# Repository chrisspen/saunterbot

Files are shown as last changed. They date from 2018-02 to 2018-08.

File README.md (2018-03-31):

Saunterbot
==========

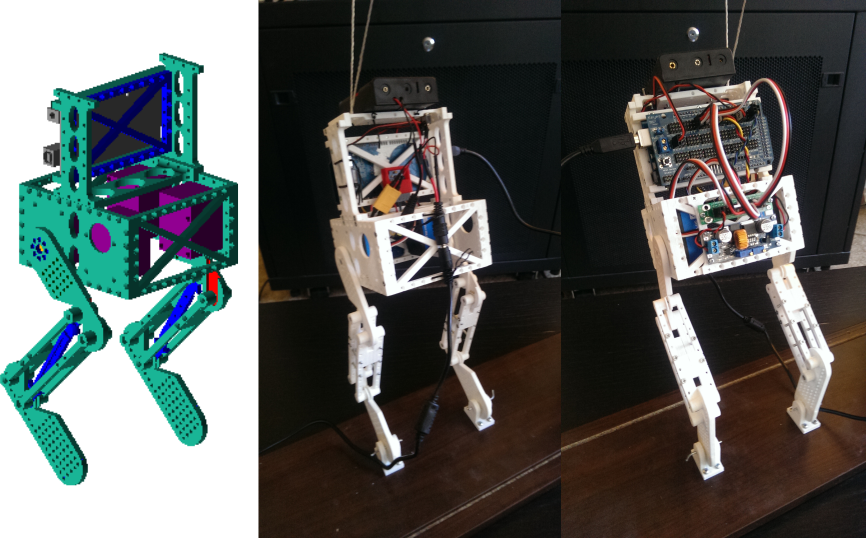
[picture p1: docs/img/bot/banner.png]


This is a small ROS-based platform for experimenting with dynamic biped balancing algorithms.

The image on the left is a CAD mock-up of the planned autonomous biped walker. On the right is the implemented version, mounted in a harness for testing its balancing ability.

An Arduino Mega is used for on-board actuation of servos and reading an MPU6050 accelerometer. It communicates to an external computer running ROS via USB for debugging and analyzing sensor output.

Once the basic balancing algorithm has been refined, the external computer will be replaced with a small single-board computer, like the Raspberry Pi, mounted in the compartment adjacent to the Arduino to make the platform fully autonomous.

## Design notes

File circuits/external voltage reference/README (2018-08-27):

Provides a stable high-accuracy voltage reference for the Arduino's ADC, using an LM4040 zener diode circuit.

http://www.skillbank.co.uk/arduino/measure.htm

The Arduino's on-board voltage references have a variance of +/- 5%.

Using the LM4040, it provides a voltage of  4.096V ± 0.2%.

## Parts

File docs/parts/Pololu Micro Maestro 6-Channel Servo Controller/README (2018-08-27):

Pololu Micro Maestro 6-Channel Servo Controller
===============================================

https://www.pololu.com/product/1350

https://www.pololu.com/docs/0J40

https://www.pololu.com/blog/456/maestro-servo-controller-arduino-library

https://github.com/pololu/maestro-arduino

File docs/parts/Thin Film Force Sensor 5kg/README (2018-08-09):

1 Pc DF 9-40 High Precise Force Sensing Resistor Thin Film Force Pressure Sensor (0-5kg)

https://www.amazon.com/Precise-Sensing-Resistor-Pressure-Sensor/dp/B07B68BHSH

Specifications:

Measuring Range: 0-500g, 0-2kg, 0-5kg, 0-10kg, 0-20kg (Optional)
Thickness: <0.25mm
Precision: ±2.5%(85% measuring range)
Repeatability: <±5.8(50% load)
Lifespan: >1million times
Initial Resistance: >10MΩ(no load)
Response Time: <1ms
Restore Time: <15ms
Test Voltage: DC 3.3V (typical)
EMI: Not generate
EDS: Not sensitive

Sensing Area Outer Diameter: 9mm
Sensing Area Inner Diameter: 7.5mm
Pin Spacing: 2.54mm

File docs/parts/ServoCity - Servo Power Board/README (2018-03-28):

ServoCity Servo Power Board

https://www.servocity.com/servo-power-board-unassembeld-with-pins-and-male-servo-leads

Product Weight  1.12 oz
Number of Channels  8 channel
Wire Gauge  22 AWG
Wire Length     6"
Max Current Per Channel     3A per channel continuous / up to 9A total

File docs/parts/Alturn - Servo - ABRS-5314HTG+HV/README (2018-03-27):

Alturn USA Servo ABRS-5314HTG+HV
================================

http://alturn-usa.com/products/PDF/ABRS-5314HTG+HV.pdf

https://www.ebay.com/itm/ABRS-5314HTG-Full-HV-Advance-Robot-Brushless-Digital-High-Voltage-HS-TG-/273065742269

https://www.robot-r-us.com/vmchk/motor-robot-servo/digital-metal-gear-ultra-high-torque-robot-servo-53-kg.cm-/-280.html

Weight:
        
    75grams / 2.60oz
    without splined horn

Dimensions:

    43 × 32× 32.5 mm
    (1.69 x 1.25 x 1.28 inch)

Torque At 7.4V:

    25.1kg/cm , 348oz/in

Speed At 7.4V:

    0.18sec / 60 deg at no load

Torque At 8.3V:

    32.4kg/cm , 466oz/in

Speed At 8.3V:

    0.16sec / 60 deg at no load

Torque At 12V:

    53.1kg/cm , 708z/in

Speed At 12V:

    0.14sec / 60 deg at no load

Motor Type:

    Japan Brushless motor

Potentiometer Type  

FSE11-4 Slider/indirect drive
Amplifier Type  6A Treble Power MOS-FET
Wire Info (Black)   - Negative
Wire Info (Red) + Positive
Wire Info (White)   S Single
Gear Types  Stainless Steel
Travel Degree   280 degree / 0.9us ~ 2.1us PWM
Operation Voltage   7.4V ~ 12V (2S ~ 3S Li Poly)

Cable pinout:

    Note, it appears to have a "J" or Futaba connector, which has a tab indicating polarity.

    Starting with notched end: white/red/black

Testing:

    At 5V, I found the servo to have an astonishing 280 degrees of rotation. However, it was also incredibly noisy.

    At 10V, I found the servo performed almost the same, but had a noticable stutter once or twice a cycle.

    input Voltage is 6.0 ~ 12.0V
    best voltage is 7.4 ~ 8.4V

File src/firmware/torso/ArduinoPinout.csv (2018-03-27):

Arduino Pin | Interruptable | Supported Modes | Mode | PWM | Function | Label | Label Color | Variable | Wire Color | Notes
D0 |  | NA | NA |  | USB
D1 |  | NA | NA |  | USB
D2 |  | input/output |  | 1
D3 |  | input/output |  | 1
D4 |  | input/output |  | 1
D5 |  | input/output |  | 1
D6 |  | input/output |  | 1
D7 |  | input/output |  | 1
D8 |  | input/output |  | 1
D9 |  | input/output |  | 1
D10 |  | input/output |  | 1
D11 |  | input/output |  | 1
D12 |  | input/output |  | 1
D13 |  | input/output |  | 1 | status LED | SL |  | STATUS_LED_PIN |  | Note, has built-in LED, so can't reliably be used as an input.
D14 |  | input/output |  |  | push button | PB1 |  | PUSH_BUTTON_PIN |  | Simple push button.
D15 |  | input/output
D16 |  | input/output
D17 |  | input/output
D18 |  | input/output
D19 |  | input/output
D20 |  | input/output |  |  | SDA |  |  |  |  | I2C
D21 |  | input/output |  |  | SCL |  |  |  |  | I2C
D22 |  | input/output
D23

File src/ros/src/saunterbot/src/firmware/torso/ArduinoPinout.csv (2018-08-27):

Arduino Pin | Interruptable | Supported Modes | Has ADC | Mode | PWM | Function | Label | Label Color | Variable | Wire Color | Implemented | Notes
D0 |  | NA |  | NA |  | USB
D1 |  | NA |  | NA |  | USB
D2 |  | input/output |  | input |  | IMU interrupt | INT |  |  | yellow | 1 | IMU interrupt.
D3 |  | input/output |  |  | 1
D4 |  | input/output |  |  | 1
D5 |  | input/output |  |  | 1
D6 |  | input/output |  |  | 1
D7 |  | input/output |  | output | 1 | servo hip right | SHR |  | SERVO_HIP_RIGHT_PIN |  | 1
D8 |  | input/output |  | output | 1 | servo hip left | SHL |  | SERVO_HIP_LEFT_PIN |  | 1
D9 |  | input/output |  | output | 1 | servo knee right | SKR |  | SERVO_KNEE_RIGHT_PIN |  | 1
D10 |  | input/output |  | output | 1 | servo knee left | SKL |  | SERVO_KNEE_LEFT_PIN |  | 1
D11 |  | input/output |  |  | 1 | servo ankle right |  |  |  |  | 0
D12 |  | input/output |  |  | 1 | servo ankle left |  |  |  |  | 0
D13 |  | input/output |  | output | 1 | status LED | SL |  | STATUS_LED_PIN |  | 1 | Note, has built-in LED, so can't reliably be used as an input.
D14 |  | input/output
D15 |  | input/output
D16 |  | input/output
D17 |  | input/output |  | input |  | push button | PB1 |  | PUSH_BUTTON_PIN |  | 1 | Simple push button.
D18 |  | input/output |  |  |  |  |  |  |  |  |  | TX (required for Maestro)
D19 |  | input/output |  |  |  |  |  |  |  |  |  | RX (optional for Maestro)
D20 |  | input/output |  | I2C |  | SDA | SDA |  |  | green | 1 | I2C, IMU
D21 |  | input/output |  | I2C |  | SCL | SCL |  |  | blue | 1 | I2C, IMU
D22 |  | input/output
D23 |  | input/output
A0 |  | input/output | 1
A1 |  | input/output | 1
A2 |  | input/output | 1
A3 |  | input/output | 1
A4 |  | input/output | 1 | input |  | feedback hip right | FHR |  | FEEDBACK_HIP_RIGHT_PIN | green | 1
A5 |  | input/output | 1 | input |  | feedback hip left | FHL |  | FEEDBACK_HIP_LEFT_PIN | green | 1
A6 |  | input/output | 1 | input |  | feedback knee right | FKR |  | FEEDBACK_KNEE_RIGHT_PIN | green | 1
A7 |  | input/output | 1 | input |  | feedback knee left | FKL |  | FEEDBACK_KNEE_LEFT_PIN | green | 1
A8 |  | input/output | 1 | input |  | feedback knee deflection right | KDR |  | FEEDBACK_KNEE_DEFLECTION_RIGHT_PIN | white | 1
A9 |  | input/output | 1 | input |  | feedback knee deflection left | KDL |  | FEEDBACK_KNEE_DEFLECTION_LEFT_PIN | white | 1
A10 |  | input/output | 1
A11 |  | input/output | 1
A12 |  | input/output | 1
A13 |  | input/output | 1
A14 |  | input/output | 1
A15 |  | input/output | 1

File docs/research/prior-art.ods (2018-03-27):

Name | DOF per leg | Number of legs | Balancing | Complete | URL
Rofi | 6 | 2 | static | 1 | http://www.projectbiped.com/prototypes/rofi
Fobo | 4 | 2 | static | 1 | http://www.projectbiped.com/prototypes/fobo
Kame | 2 | 4 | static | 1 | https://www.thingiverse.com/thing:1265766
Experimental Quadraped | 2 | 4 | unknown | 0 | https://www.thingiverse.com/thing:652121
Eyepot | 2 | 4 | static | 1 | https://www.thingiverse.com/thing:2830304

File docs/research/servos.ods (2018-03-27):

Score | Name | Price | Speed (sec/90deg) | Torque (kg*cm) | Voltage | Metal Gears | URL | Notes
1.27 | ABRS-5314HTG+Full HV | $48 | 0.14 | 53 | 12 | 1 | https://www.ebay.com/itm/ABRS-5314HTG-Full-HV-Advance-Robot-Brushless-Digital-High-Voltage-HS-TG-/273065742269
1.12 | Digital Metal Gear Ultra High Torque Robot Servo 53 | $70 | 0.14 | 53.1 | 12 | 1 | https://www.robot-r-us.com/vmchk/motor-robot-servo/digital-metal-gear-ultra-high-torque-robot-servo-53-kg.cm-/-280.html | Only have one left I stock. Of course... alturn usa servo 53 280
1.09 | ABRS-8034HTG+Full HV | $58 | 0.18 | 80 | 12 | 1 | https://www.ebay.com/itm/ABRS-8034HTG-HV-Duty-Heavy-Robot-Brushless-Digital-High-Voltage-HS-TG-/273065742956
0.00 | Power HD 1235MG | $60 | 0.18 | 40 | 7.4 | 1 | https://www.pololu.com/product/2375
0.00 | FEETECH FT5335M | $40 | 0.18 | 40 | 7.4 | 1 | https://www.pololu.com/product/3429
0.00 | HS-7950TH | $150 | 0.13 | 35 | 7.4 | 1 | https://www.servocity.com/hs-7950th-servo
-0.25 | CM-D950TW-180 Servo Gearbox | $208 | 0.28 | 70 | 7.4 | 1 | https://www.servocity.com/cm-d950tw-180-servo-gearbox#197=7&198=9&439=475&440=476
-0.46 | CM-9380TH-180 Servo Gearbox 2:1 | $240 | 0.28 | 69 | 7.4 | 1 | https://www.servocity.com/cm-9380th-180-servo-gearbox#197=7&198=9&439=475&440=476 | Price servo=180, price gearbox=100 => total=280
-0.60 | 4.5-9380TH-180 Servo Gearbox | $260 | 0.28 | 68 | 7.4 | 1 | https://www.servocity.com/4-5-9380th-180-servo-gearbox
-0.81 | TM-805MG-180 Servo Gearbox | $170 | 0.53 | 94 | 6 | 1 | https://www.servocity.com/tm-805mg-180-servo-gearbox
-0.83 | i00800 Torxis Servo | $290 | 0.75 | 1600 | 12 | 1 | https://www.pololu.com/product/1391
-1.42 | HS-1005SGT Servo | $435 | 0.19 | 110 | 14.8 | 1 | https://www.servocity.com/hs-1005sgt-servo
-1.57 | 4.5-D645MW-180 Tube Mount Servo Gearbox | $120 | 0.85 | 65 | 7.4 | 1 | https://www.servocity.com/4-5-d645mw-180-tube-mount-servo-gearbox#197=4&198=9&439=475&440=476
-1.86 | HS-1100WP Servo | $500 | 0.19 | 110 | 14.8 | 1 | https://www.servocity.com/hs-1100wp-servo
-2.70 | CM-785HB Servo Gearbox | $130 | 1.17 | 66 | 6 | 1 | https://www.servocity.com/cm-785hb-servo-gearbox

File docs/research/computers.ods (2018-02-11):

score | name | available | cost | cpu cores | cpu ghz | arch type | arch bits | memory type | memory GB | video | wifi | bluetooth | ethernet | powered from usb | usb | usb type | audio | mic | storage type | max storage (GB) | width (mm) | depth (mm) | area (mm^2) | power voltage | power mA | power watts | pin voltage | SATA | micro SD | arduino compatible | digital pins | analog pins | GVS | URL
26.35 | Raspberry Pi 3 | 1 | $35 | 4 | 1.2 | ARM | 64 | DDR2 | 1 | HDMI | 1 | 1 | 1 | 1 | 4 | 2 | 1 | 1 | micro SD | 64 | 85 | 56 | 4760 | 5 | 700 | 3.5 | 3.3 | 0 | 1 | 0 | 40 | 0 | 1 | https://www.raspberrypi.org/blog/raspberry-pi-3-on-sale/
23.64 | Raspberry Pi 2 Model B | 1 | $35 | 4 | 0.9 | ARM | 32 | DDR2 | 1 | HDMI | 0 | 0 | 1 | 1 | 4 | 2 | 1 | 0 | micro SD | 64 | 86 | 56 | 4816 | 5 | 700 | 3.5 | 3.3 | 0 | 1 | 0 | 40 | 0 | 1 | http://www.raspberrypi.org/products/raspberry-pi-2-model-b/
23.05 | Odroid-C1 | 1 | $35 | 4 | 1.5 | ARM | 32 | DDR3 | 1 | HDMI | 0 | 0 | 1 | 0 | 4 |  | 1 | 0 | micro SD | 64 | 85 | 56 | 4760 | 5 | 500 | 2.5 | 3.3 | 0 | 1 | 0 | 40 | 2 | 1 | http://www.hardkernel.com/main/products/prdt_info.php
22.28 | Orange Pi 2 | 1 | $35 | 4 | 1.6 | ARM | 32 | DDR3 | 1 | HDMI | 1 | 0 | 1 | 1 | 4 | 2 | 1 | 1 | micro SD | 64 | 60 | 93 | 5580 | 5 | 700 | 3.5 | 3.3 |  | 1 | 0 | 40 | 0 | 0 | http://www.cnx-software.com/2015/03/21/orange-pi-2-allwinner-h3-quad-core-development-board-sells-for-35/
20.78 | Orange Pi | 1 | $15 | 4 | 1.6 | ARM | 32 | DDR3 | 1 | HDMI | 0 | 0 | 1 | 1 | 3 | 2 | 1 | 1 | micro SD | 64 | 60 | 93 | 5580 | 5 | 700 | 3.5 | 3.3 |  | 1 | 0 | 40 | 0 | 0 | http://liliputing.com/2015/08/orange-pi-pc-is-a-15-single-board-computer.html
20.33 | UDOO Dual Basic | 1 | $100 | 2 | 1 | ARM | 32 | DDR3 | 1 | HDMI | 0 | 0 | 1 | 1 | 2 |  | 1 | 1 | micro SD | 64 | 110 | 85 | 9350 | 5 | 660 | 3.3 | 3.3 | 0 | 1 | 1 | 62 | 14 | 1 | http://shop.udoo.org/usa/product/udoo-dual-basic.html
15.06 | Beagle Bone Black | 1 | $45 | 1 | 1 | ARM | 32 | DDR3 | 0.5 | HDMI | 0 | 0 | 1 | 1 | 1 |  | 1 | 0 | micro SD | 64 | 87 | 54 | 4698 | 5 | 500 | 2.5 | 3.3/5 | 0 | 1 | 0 | 65 | 7 | 0.5 | http://beagleboard.org/BLACK
9.43 | PCDuino3 | 1 | $60 | 1 | 1 | ARM | 32 | DRAM | 1 | HDMI | 0 | 0 | 1 | 1 | 1 |  | 1 | 0 | micro SD | 64 | 121 | 65 | 7865 | 5 | 2000 | 10 | 3.3 | 1 | 1 | 1 | 14 | 6 | 1 | http://www.sainsmart.com/arduino/control-boards/pcduino3.html
5.00 | Arduino TRE | 0 |  | 1 | 1 | ARM | 32 | DDR3 | 0.5 | HDMI | 0 | 0 | 1 | 1 | 4 |  | 1 | 0 | micro SD | 64 |  |  | 0 |  |  | 0 | 3.3/5 | 0 | 1 | 1 | 14 | 6 | 1 | http://arduino.cc/en/Main/ArduinoBoardTre
5.00 | Arduino Yun | 0 | $58 | 1 | 0.4 | MIPS | 32 | DDR2 | 0.064 | 0 | 1 | 0 | 1 | 1 | 1 |  | 0 | 0 | micro SD | 64 | 73 | 53 | 3869 | 5 | 300 | 1.5 | 3.3 | 0 | 1 | 1 | 20 | 12 | 1 | http://arduino.cc/en/Main/ArduinoBoardYun?from=Products.ArduinoYUN
0.36 | Intel Galileo Gen 1 | 1 | $80 | 1 | 0.4 | x86 | 32 | DRAM | 0.25 | 0 | 0 | 0 | 1 | 1 | 1 |  | 0 | 0 | micro SD | 64 | 124 | 72 | 8928 | 5 | 3000 | 15 | 3.3/5 | 0 | 1 | 1 | 14 | 6 | 1
0.36 | Intel Galileo Gen 2 | 1 | $80 | 1 | 0.4 | x86 | 32 | DRAM | 0.25 | 0 | 0 | 0 | 1 | 1 | 1 |  | 0 | 0 | micro SD | 64 | 124 | 72 | 8928 | 5 | 3000 | 15 | 3.3/5 | 0 | 1 | 1 | 14 | 6 | 1 | http://arduino.cc/en/ArduinoCertified/IntelGalileo
-138.81 | AIMB-281G2-00A1E Mini-ITX | 1 | $241 | 4 | 3.9 | x86 | 64 | DDR3 | 8 | VGA/DVI | 0 | 0 | 1 | 1 | 8 | 2 | 1 | 1 | micro SD | 64 | 170 | 170 | 28900 |  |  | 186.127 |  | 1 | 0 | 0 | 0 | 0 | 0 | http://buy.advantech.com/Mini+ITX+industrial+motherboard/AIMB+281G2+00A1E/model-AIMB-281G2-00A1E.htm

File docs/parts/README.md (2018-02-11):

Folder Format
-------------

Manufacturer - Product - Version

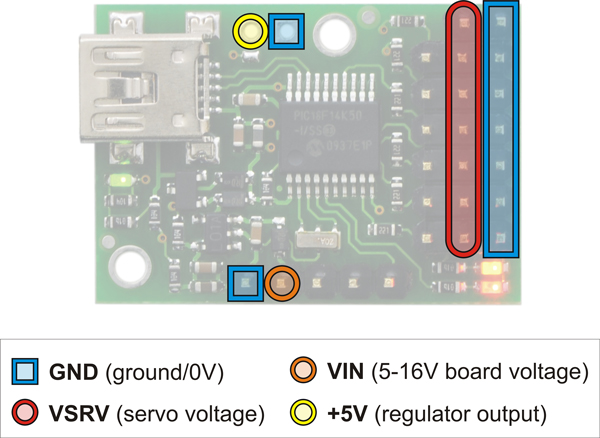
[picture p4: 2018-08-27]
docs/parts/Pololu Micro Maestro 6-Channel Servo Controller/0J2352.1200.jpg

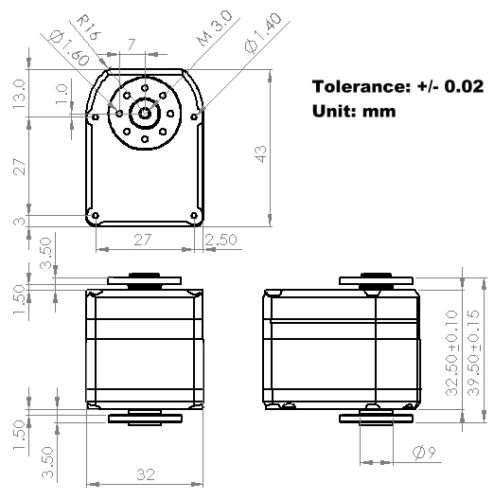
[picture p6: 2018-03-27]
docs/parts/Alturn - Servo - ABRS-5314HTG+HV/s-l500.jpg

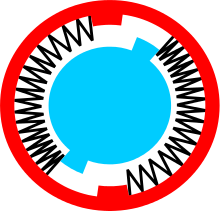
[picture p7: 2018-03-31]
docs/parts/Servo Saver/DMF.svg.png

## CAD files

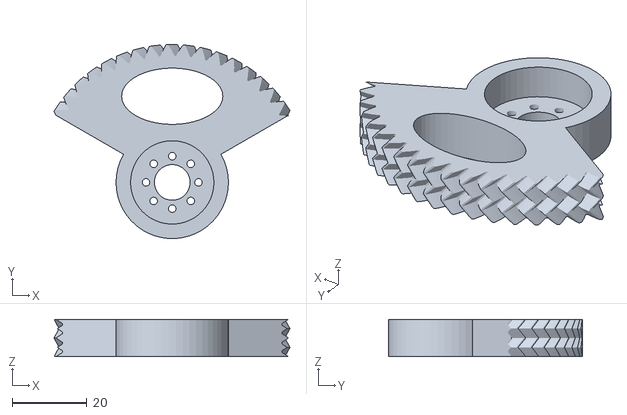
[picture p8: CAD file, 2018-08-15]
models/printable/leg_hip_gear_main.stl
63.0 x 51.8 x 10.0

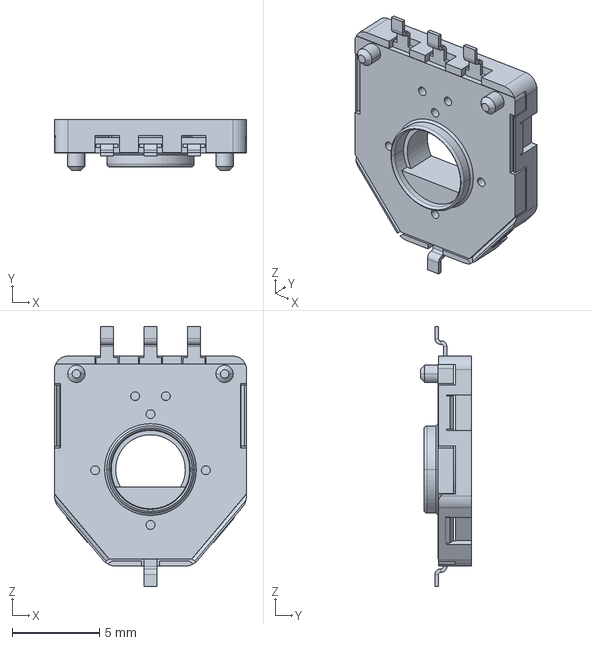
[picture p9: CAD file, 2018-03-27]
docs/parts/Rotary Position Sensor - Model 3382/3382g-001-xxx.stp
11.0 x 2.95 x 14.9 mm

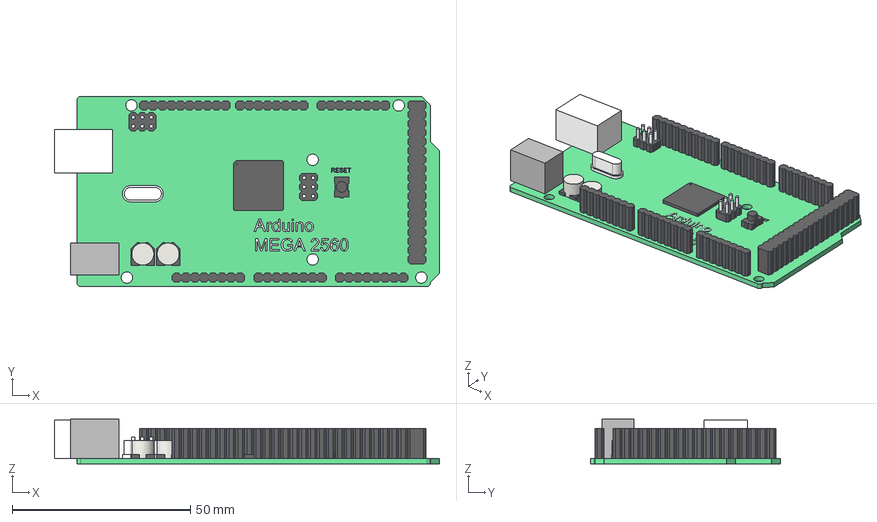
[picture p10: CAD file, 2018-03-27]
models/electronics/arduino-mega-2560/ArduinoMEGA2560.stp
107.9 x 53.3 x 12.6 mm

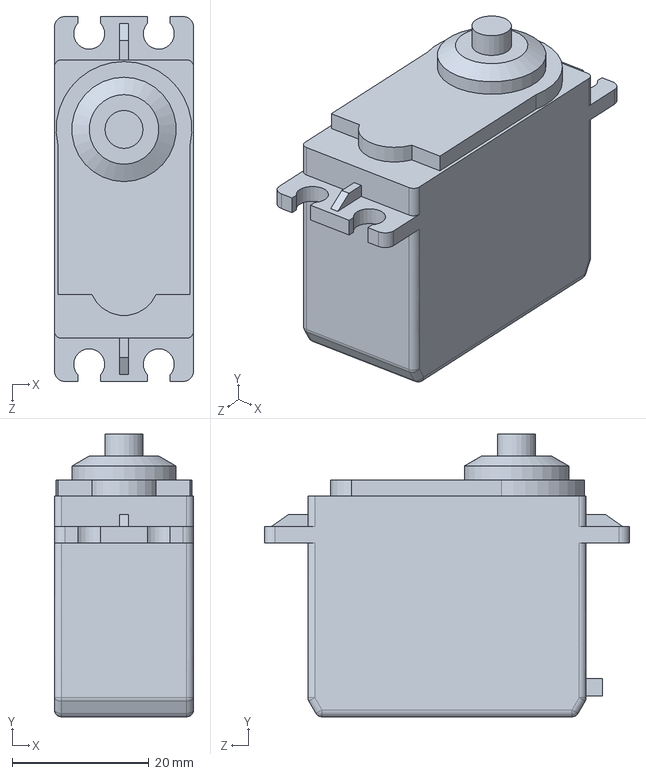
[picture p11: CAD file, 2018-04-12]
models/electronics/hs-311-hitec-standard-servo/HS-311 Hitec Standard Servo.SLDPRT
20.3 x 41.3 x 53.3 mm

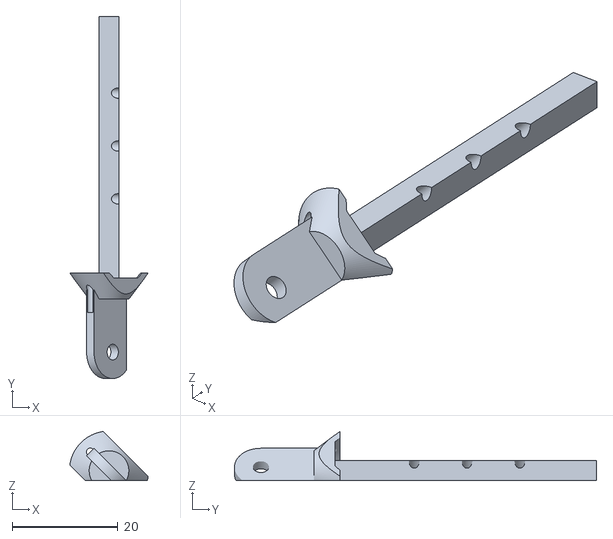
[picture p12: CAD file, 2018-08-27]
models/printable/leg_spring2_male.stl
14.8 x 68.5 x 9.30

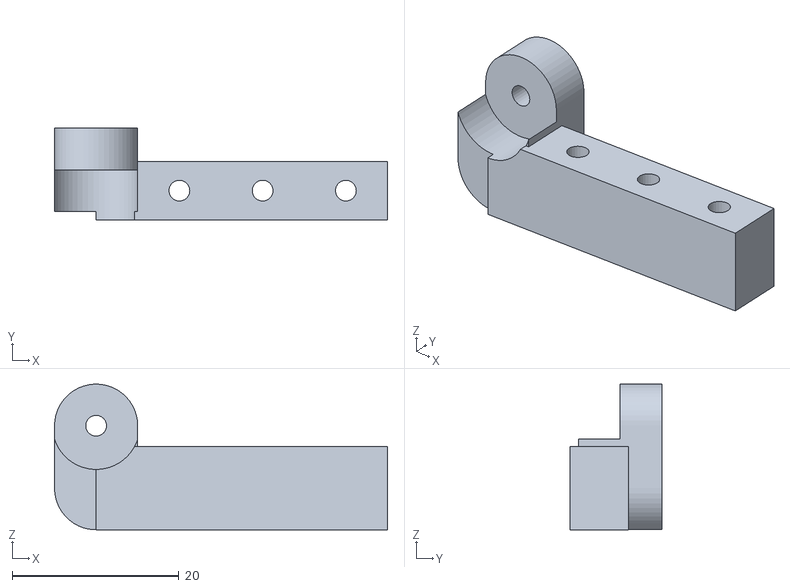
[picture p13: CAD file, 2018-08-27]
models/printable/leg_spring_hinge_extender.stl
40.0 x 11.0 x 17.5

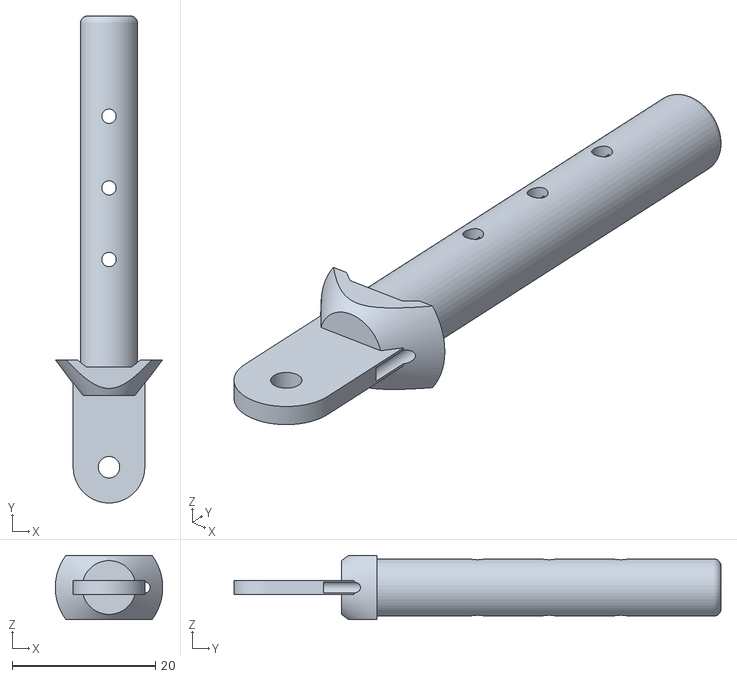
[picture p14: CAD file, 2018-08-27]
models/printable/leg_spring2_female.stl
15.0 x 68.0 x 9.00

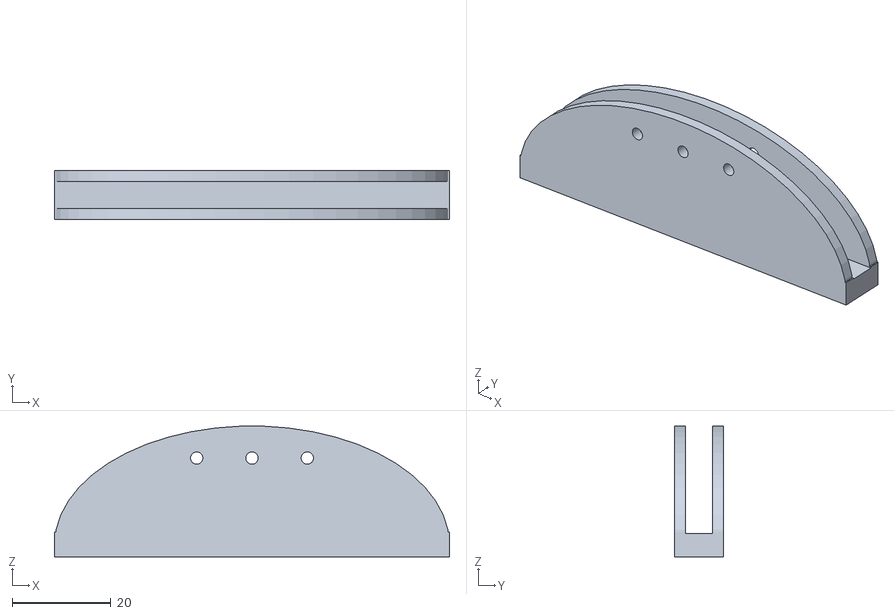
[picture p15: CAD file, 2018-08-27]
models/printable/foot_mock.stl
80.0 x 10.0 x 26.5

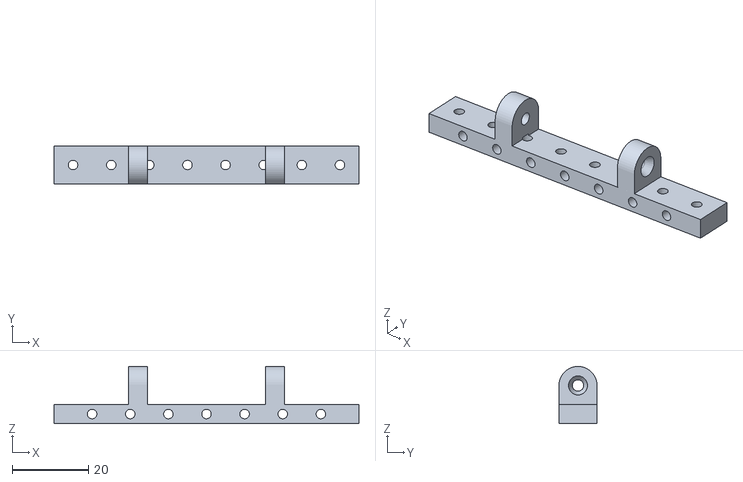
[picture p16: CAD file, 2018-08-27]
models/printable/foot_mock_core.stl
80.0 x 10.0 x 15.0

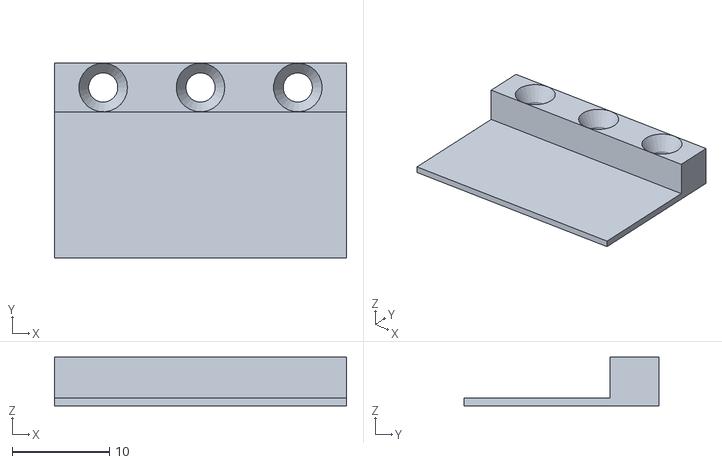
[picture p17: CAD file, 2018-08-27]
models/printable/foot_mock_toe_spring.stl
30.0 x 20.0 x 5.00

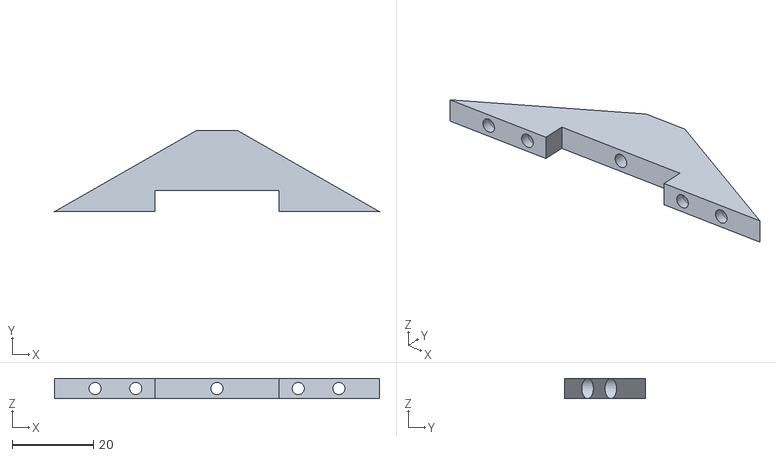
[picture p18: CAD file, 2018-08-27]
models/printable/foot_mock_toe.stl
80.0 x 20.0 x 5.00

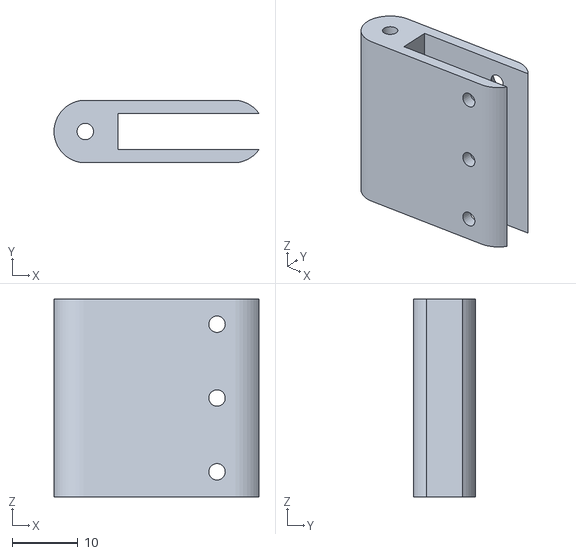
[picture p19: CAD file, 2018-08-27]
models/printable/foot_mock_ankle.stl
31.1 x 9.48 x 30.0

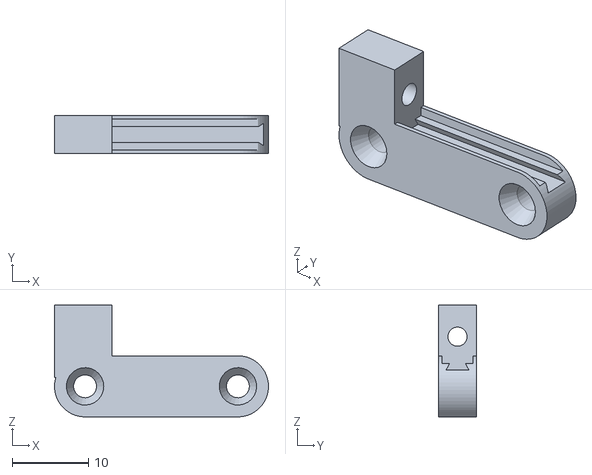
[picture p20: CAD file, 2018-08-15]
models/printable/leg_knee_tendon_anchor_bottom.stl
28.0 x 5.00 x 14.6

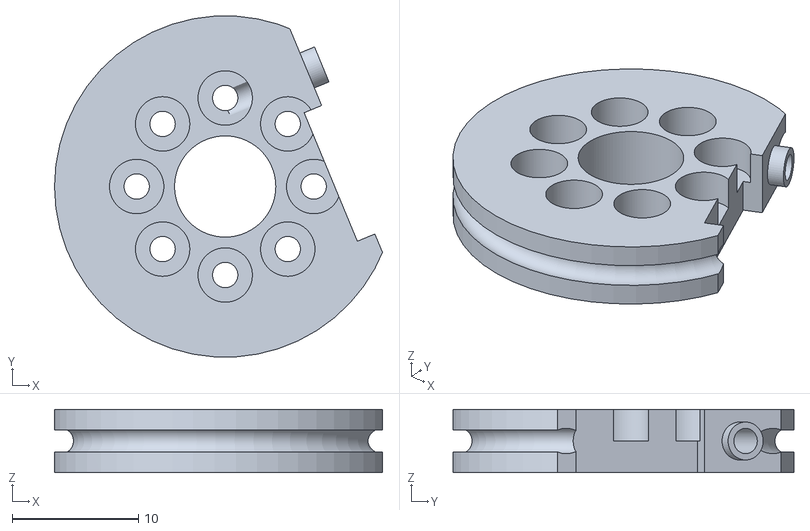
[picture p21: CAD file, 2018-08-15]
models/printable/leg_knee_servo_spindle.stl
25.9 x 26.9 x 5.00

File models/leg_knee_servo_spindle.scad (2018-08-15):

use <leg_knee_servo_riser.scad>;

rotate([0,180,0])
leg_knee_servo_spindle();

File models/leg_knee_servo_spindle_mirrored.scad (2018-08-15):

use <leg_knee_servo_riser.scad>;

mirror([0,0,1])
rotate([0,180,0])
leg_knee_servo_spindle();

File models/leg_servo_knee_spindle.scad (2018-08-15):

use <leg_knee_servo_riser.scad>;

leg_knee_servo_horn();

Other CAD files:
models/sensor.stl
models/printable/leg_spring_hinge_extender_mirrored.stl
models/printable/leg_spring.stl
models/printable/leg_hip_axle_round.stl
models/gears/parametric_involute_gear_v5.0.scad
models/arduino_mega_mount.scad
models/arduino_mega_mount_bottom.scad
models/arduino_mega_mount_top.scad
models/balancer.scad
models/balancer_bottom_plate.scad
models/balancer_drive_gear.scad
models/balancer_gear_axle_top.scad
models/balancer_gear_washer.scad
models/balancer_middle_plate.scad
models/balancer_opposite_gear.scad
models/balancer_top_plate.scad
models/balancer_translation_gear.scad
models/balancer_weight_container.scad
models/balancer_weight_container_door.scad
models/battery_holder_strut.scad
models/dc_converter_tray.scad
models/electronics/arduino-mega-2560/ArduinoMEGA2560.ipt
models/electronics/arduino-mega-2560/Arduino_MEGA2560.stl
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

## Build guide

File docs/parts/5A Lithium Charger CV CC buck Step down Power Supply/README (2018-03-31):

When you use the product, the module inputs and outputs to be isolated from ground！
Specifications
1、Input voltage range:6～38VDC(Note:input voltage not exceeding 38V)
2、Output voltage range:1.25-36VDC adjustable
3、Output current: 0-5A
4、Output power: 75W
5、High efficiency up to 96%
6、Built in thermal shutdown function
7、Built in current limit function
8、Built in output short protection function
9、Input reverse polarity protection: None (if required, high current diode in series with the input).
10、L x W x H =61.7*26.2*15mm
11、Weight: 20g

Application
1、Use as a step-down modules with overcurrent protection capabilities
Usage:
(1) adjust the “voltage potentiometer” so that the output voltage reaches the value you want.
(2) use a multimeter to measure the output short-circuit current with 10A stalls, while regulating the “current potentiometer” so that the output current reaches a predetermined overcurrent protection value. (For example, the meter displays the current value of 4A, then you can use the module to a maximum current of 4A)
(3) Connected to the load.

2、Use as a battery charger
Usage:
(1). Make sure you need to charge the battery float voltage and charging current; (if lithium parameters 3.7V/2200mAh, then the float voltage is 4.2V, the maximum charging current 1C, ie 2200mA)
(2). Under no-load conditions, adjust the “Voltage potentiometer” so that the output voltage reaches the float voltage; (if to 3.7V rechargeable lithium battery, the output voltage can be adjusted to 4.2V)
(3). use a multimeter to measure the output short-circuit current with 10A stalls, while regulating the “current potentiometer” so that the output current reaches a predetermined Charging current value.
(4). Charge turn lamp current factory default is 0.1 times the charging current; (Battery during charging current is gradually reduced, if the charge current setting is 1A, then when the charge current is less than 0.1A, blue lights turned off, the green light is on, which means that the battery is fully charged)
(5).connected to the battery charge.
(1,2,3,4 steps as: Output is unloaded, do not connect the battery)

3、Use as a LED constant current driver module
Usage:
(1). adjust the “voltage potentiometer” so that the output voltage reaches the value you want.
(2). use a multimeter to measure the output short-circuit current with 10A stalls, while regulating the “current potentiometer” so that the output current reaches a predetermined LED operating current.
(3). Connect LED, work.
(1,2 steps as: Output is unloaded, do not connect LED)

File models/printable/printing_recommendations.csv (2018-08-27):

filename | wall_thickness | color | infill_percent | platform_adhesion | support_type | obsolete
arduino_mega_mount.stl |  |  |  |  |  | 0
arduino_mega_mount_bottom.stl |  |  |  |  |  | 0
arduino_mega_mount_top.stl |  |  |  |  |  | 0
balancer_bottom_plate.stl |  |  |  |  |  | 0
balancer_drive_gear.stl |  |  |  |  |  | 0
balancer_gear_axle_top.stl |  |  |  |  |  | 0
balancer_gear_washer.stl |  |  |  |  |  | 0
balancer_middle_plate.stl |  |  |  |  |  | 0
balancer_opposite_gear.stl |  |  |  |  |  | 0
balancer_top_plate.stl |  |  |  |  |  | 0
balancer_translation_gear.stl |  |  |  |  |  | 0
balancer_weight_container.stl |  |  |  |  |  | 0
balancer_weight_container_door.stl |  |  |  |  |  | 0
battery_holder_strut.stl |  |  |  |  |  | 0
dc_converter_tray.stl |  |  |  |  |  | 0
foot_mock.stl |  |  |  |  |  | 0
foot_mock_ankle.stl |  |  |  |  |  | 0
foot_mock_core.stl |  |  |  |  |  | 0
foot_mock_toe.stl |  |  |  |  |  | 0
foot_mock_toe_spring.stl |  |  |  |  |  | 0
foot_pivot.stl |  |  |  |  |  | 0
leg_hip_axle.stl |  |  |  |  |  | 0
leg_hip_axle_round.stl |  |  |  |  |  | 0
leg_hip_gear_main.stl |  |  |  |  |  | 0
leg_hip_gear_main_34.stl |  |  |  |  |  | 1
leg_hip_holder.stl |  |  |  |  |  | 0
leg_hip_spacer.stl |  |  |  |  |  | 0
leg_hip_tendon_retainer.stl |  |  |  |  |  | 0
leg_knee_servo_riser.stl |  |  |  |  |  | 0
leg_knee_servo_spindle.stl |  |  |  |  |  | 0
leg_knee_servo_spindle_mirrored.stl |  |  |  |  |  | 0
leg_knee_tendon_anchor_bottom.stl |  |  |  |  |  | 0
leg_knee_tendon_anchor_bottom_mirrored.stl |  |  |  |  |  | 0
leg_knee_tendon_anchor_top.stl |  |  |  |  |  | 0
leg_lower.stl |  |  |  |  |  | 0
leg_middle.stl |  |  |  |  |  | 0
leg_middle_bottom_a.stl |  |  |  |  |  | 0
leg_middle_bottom_b.stl |  |  |  |  |  | 0
leg_middle_top_a.stl |  |  |  |  |  | 0
leg_middle_top_b.stl |  |  |  |  |  | 0
leg_servo_knee_spindle.stl |  |  |  |  |  | 1
leg_spring.stl |  |  |  |  |  | 0
leg_spring2.stl |  |  |  |  |  | 0
leg_spring2_female.stl |  |  |  |  |  | 0
leg_spring2_male.stl |  |  |  |  |  | 0
leg_spring_hinge_extender.stl |  |  |  |  |  | 0
leg_spring_hinge_extender_mirrored.stl |  |  |  |  |  | 0
leg_upper.stl |  |  |  |  |  | 0
leg_upper_mirrored.stl |  |  |  |  |  | 0
motors_alturn_abrs_5314htg_hv.stl |  |  |  |  |  | 0
pelvis_cross_support.stl |  |  |  |  |  | 0
pelvis_motor_face.stl |  |  |  |  |  | 0
pelvis_motor_face_mirrored.stl |  |  |  |  |  | 0
pelvis_torso_strut.stl |  |  |  |  |  | 0
torso_side.stl |  |  |  |  |  | 0

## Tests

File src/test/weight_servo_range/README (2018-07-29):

Sweeps the servo across its range when a button is pressed.

Compile and upload with:

    make && make upload

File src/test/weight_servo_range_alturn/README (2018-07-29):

Sweeps the servo across its range when a button is pressed.

Specialized for use with the heavy duty Alturn servo.

Compile and upload with:

    make && make upload

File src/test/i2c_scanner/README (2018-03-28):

Scans all devices on the I2C bus and prints their addresses to the serial port.

This is used to verify that the MPU6050 is correctly wired and responded to requests at the expected 0x68 address.

Build:

    makee && make upload

Run:

    make monitor

To exit:

    ctrl-a, then k, then "yes"

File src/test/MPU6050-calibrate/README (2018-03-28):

http://wired.chillibasket.com/2015/01/calibrating-mpu6050/

FOR CALIBRATION THE SENSOR MUST BE PLACED FLAT WITH Z POINTING UP.

The sketch outputs the required accelerometer and gyroscope offsets through the serial monitor. All you have to do is plug them into the initialisation code at the start of your program, and you are good to go! Please note that the required offsets vary significantly from sensor to sensor, so you have to repeat the calibration program above for each MPU-6050 sensor you are using.

Sensor readings with offsets:   7   -9  16375   0   -1  0
Your offsets:   -3984   -525    -849    17  147 54

Data is printed as: acelX acelY acelZ giroX giroY giroZ
Check that your sensor readings are close to 0 0 16384 0 0 0
If calibration was succesful write down your offsets so you can set them in your projects using something similar to mpu.setXAccelOffset(youroffset)

Test these values in MPU6050-read.

All of the values float a large amount at the start, especially the yaw data. This then stops after around 13 seconds, probably due to the completion of some auto-calibration process. I repeated this test a number of times and it seems that the sensor can take up to 40 seconds to complete its calibration, on some occasions. Therefore we should take this delay into account in our program. The robot should wait for around 40 seconds, before beginning to use the sensor and starting the main program.

Build:

    make && make upload

Run:

    make monitor

To exit:

    ctrl-a, then k, then "yes"

Note, depending on your specific device, the "Calculating offsets..." part may take a few minutes.

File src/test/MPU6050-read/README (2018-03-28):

http://wired.chillibasket.com/2015/01/calibrating-mpu6050/

Here is the code that I used to get the yaw, pitch and roll sensor data. It is based on the “Teapot” demonstration program which comes with the MPU-6050 Motion Apps library. Once again, you need to have the “MPU6050” and the “I2Cdev” libraries installed to use this code.

Build:

    make && make upload

Run:

    make monitor

To exit:

    ctrl-a, then k, then "yes"

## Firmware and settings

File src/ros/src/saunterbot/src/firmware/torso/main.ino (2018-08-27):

/*
 * Copyright 2017 Chris Spencer
 */
 
#include <ros.h>
// http://wiki.ros.org/std_msgs
#include <std_msgs/Bool.h>
#include <std_msgs/Int16.h>
#include <std_msgs/Int32.h>
#include <std_msgs/Empty.h>
#include <std_msgs/Float32MultiArray.h>
#include <std_msgs/Float32.h>

//#include <Servo.h>

#include "ArduinoPinout.h"
#include "AccelGyroSensor.h"
#include "PIDController.h"
#include "ServoController.h"
#include "BalanceController.h"
#include "EEPROMAnything.h"
#include "VelocityTracker.h"
#include "ADCTracker.h"

//#define BAUDRATE 115200 // causes occassional "Lost sync with device, restarting" errors?
//#define BAUDRATE 57600
#define BAUDRATE 76800

#define MAX_OUT_CHARS 255

// Absolute min of Alturn servos, not taking into account physical leg limitations.
#define SERVO_LOWER_ABS 1000

// Absolute center of Alturn servos.
#define SERVO_CENTER_ABS 1500

// Absolute max of Alturn servos, not taking into account physical leg limitations.
#define SERVO_UPPER_ABS 2000

// Absolute min of Alturn servos, taking into account physical limits of legs.
// TODO:add more leg clearance? this limitation is mostly due to the right-knee running into the torso
#define SERVO_LOWER_PHY_RIGHT 1000//1275 // THIS IS A HARD LIMIT FOR THE RIGHT. Passing this will block the servo and possibly damage it!!!
#define SERVO_LOWER_PHY_LEFT 1000//1275 // practical limit, going beyond this won't damage the leg, but the leg won't respond

// Absolute max of Alturn servos, taking into account physical limits of legs.
#define SERVO_UPPER_PHY_RIGHT 2000//1525
#define SERVO_UPPER_PHY_LEFT 2000//1725 // THIS IS A HARD LIMIT FOR THE LEFT. Passing this will block the servo and possibly damage it!!!

// Amount of offset in degrees so the right servo matches the left.
#define SERVO_HIP_LEFT_OFFSET 0 //20

// The pitch angle above which the servos shutoff for safety.
#define SERVO_SHUTOFF_BACKWARDS_ANGLE 15

// The upper (leg's back) most practical range for balancing in the context of the right leg.
//#define SERVO_BALANCING_UPPER 1460

// The position where the leg's are roughly underneath the center-of-mass in the context of the right leg.
//#define SERVO_BALANCING_CENTER 1375

// The lower (leg's forward) most practical range for balancing in the context of the right leg.
//#define SERVO_BALANCING_LOWER 1290

// The ratio used to convert degrees to a relative servo position.
//#define SERVO_DEGREE_TO_POSITION 170.0/43.0

// On left:
//1500->1750 upper max => CW
//1500->1100 lower min => CCW
// On right:
//1500->1750 upper max => CW
//1500->1275 lower min => CCW
// Both have a physical range of 225 on either side of 1500.

char buffer[MAX_OUT_CHARS + 1];  //buffer used to format a line (+1 is for trailing 0)

ros::NodeHandle nh;

AccelGyroSensor ag_sensor = AccelGyroSensor();

VelocityTracker foot_tracker = VelocityTracker();

PIDController hip_pid_controller = PIDController(SERVO_LOWER_PHY_RIGHT, SERVO_UPPER_PHY_LEFT);

ADCTracker knee_left_adc = ADCTracker(FEEDBACK_KNEE_DEFLECTION_LEFT_PIN, true);
ADCTracker knee_right_adc = ADCTracker(FEEDBACK_KNEE_DEFLECTION_RIGHT_PIN, true);

unsigned long last_ag_read_time = 0;
unsigned long mpu_read_count = 0;
unsigned long last_blink_time = 0;
unsigned long last_heartbeat_time = 0;
unsigned long heartbeat_count = 0;
unsigned long foot_log_time = 0;
unsigned long last_aaread_time = 0;

int diff_acc_z = 0;
int last_acc_z = 0;

bool angle_safety_shutoff_enabled = false;

char x_str[20];
char y_str[20];
char z_str[20];

char yaw_str[20];
char pitch_str[20];
char roll_str[20];
char d_str[20];
char e_str[20];
//char x2_str[10];
//char y2_str[10];
//char z2_str[10];

std_msgs::Bool bool_msg;
std_msgs::Int32 int32_msg;
std_msgs::Float32MultiArray float32ma_msg;
//float state_data[] = {0, 0, 0, 0};

// Persistent variables.
struct config_t
{
    int servo_hip_right_lower_pos_feedback;
    int servo_hip_right_upper_pos_feedback;
    int servo_hip_left_lower_pos_feedback;
    int servo_hip_left_upper_pos_feedback;
    
    // NN controller.
    float w_yeta;
    float w_yeta_dot;
    float w_theta;
    float w_theta_dot;
    float w_zeta;

    // PID controller.
    float Kp = 0;                   // (P)roportional Tuning Parameter
    float Ki = 0;                   // (I)ntegral Tuning Parameter        
    float Kd = 0;                  // (D)erivative Tuning Parameter       
    
    int knee_left_adc_min_value = 10000;
    int knee_left_adc_max_value = 0;
    int knee_right_adc_min_value = 10000;
    int knee_right_adc_max_value = 0;
    float knee_left_adc_offset = 0;
    float knee_right_adc_offset = 0;
    
} configuration;

// Function declarations.
void reset_hip_position();

//Servo servo_hip_right;
//Servo servo_hip_left;
//ServoController servo_weight_shifter = ServoController(SERVO_WEIGHT_SHIFTER_OUTPUT_PIN, 1000-100, 2000+100, 1500, SERVO_WEIGHT_SHIFTER_INPUT_PIN);
ServoController servo_hip_right_controller = ServoController(SERVO_HIP_RIGHT_PIN, 1000, 2000, 1500, FEEDBACK_HIP_RIGHT_PIN);
ServoController servo_hip_left_controller = ServoController(SERVO_HIP_LEFT_PIN, 1000, 2000, 1500, FEEDBACK_HIP_LEFT_PIN);

ServoController servo_knee_right_controller = ServoController(SERVO_KNEE_RIGHT_PIN, 1000+50, 2000-50, 1500, FEEDBACK_KNEE_RIGHT_PIN);
ServoController servo_knee_left_controller = ServoController(SERVO_KNEE_LEFT_PIN, 1000+50, 2000-50, 1500, FEEDBACK_KNEE_LEFT_PIN);

BalanceController balance_controller = BalanceController();
float balance_action;

int servo_hip_right_pos = SERVO_CENTER_ABS;
int servo_hip_left_pos = SERVO_CENTER_ABS;
int center = 90;
int range = 30;
int offset = 0;
int upper_endstop = center + range + offset;
int lower_endstop = center - range + offset;
int servo_update_speed_ms = 30; // ms between step
int servo_direction = +1;

bool last_angle_safety_shutoff;

int current_hip_angle = 0;
int last_hip_angle = 0;

unsigned long last_servo_update_time = 0;
unsigned long servo_last_set_time = 0;
unsigned long balance_last_output_time = 0;
unsigned long balancing_started_time = 0;
unsigned long balancing_stopped_time = 0;
unsigned long last_state_publish_time = 0;

bool last_pushbutton_state = true;

// If true, pressing the button starts auto balancing. If false, pressing the button only publishes button state, but otherwise doesn't do anything.
bool balance_button_enabled = true;

bool angle_safety_shutoff = false;

bool balancing_enabled = false;

bool disabling_balancing = false;

// If true, servos are attached being sent a signal.
// Otherwise, servos are detached and not being sent a signal.
bool servo_hips_active = false;

float pitch_degrees = 0;

long ftol(float v) {
    // Assumes 3 places of decimal precision.
    // Assumes the host interpreting this number will first divide by 1000.
    return static_cast<long>(v*1000);
}

int calculate_foot_degrees(int hip_degrees, int body_degrees) {
    return (body_degrees - hip_degrees);
}

void enable_hip_servos() {
    servo_hips_active = true;
    servo_last_set_time = millis();
    servo_hip_right_controller.power_on();
    servo_hip_left_controller.power_on();
}

void disable_hip_servos() {
    servo_hips_active = false;
    servo_hip_right_controller.power_off();
    servo_hip_left_controller.power_off();
}

void save_configuration(){
    
    configuration.servo_hip_left_lower_pos_feedback = servo_hip_left_controller.get_lower_feedback_position();
    configuration.servo_hip_left_upper_pos_feedback = servo_hip_left_controller.get_upper_feedback_position();
    configuration.servo_hip_right_lower_pos_feedback = servo_hip_right_controller.get_lower_feedback_position();
    configuration.servo_hip_right_upper_pos_feedback = servo_hip_right_controller.get_upper_feedback_position();

    configuration.w_yeta = balance_controller.w_yeta;
    configuration.w_yeta_dot = balance_controller.w_yeta_dot;
    configuration.w_theta = balance_controller.w_theta;
    configuration.w_theta_dot = balance_controller.w_theta_dot;
    configuration.w_zeta = balance_controller.w_zeta;

    configuration.Kp = hip_pid_controller.Kp;
    configuration.Ki = hip_pid_controller.Ki;
    configuration.Kd = hip_pid_controller.Kd;

    configuration.knee_left_adc_min_value = knee_left_adc.min_value;
    configuration.knee_left_adc_max_value = knee_left_adc.max_value;
    configuration.knee_left_adc_offset = knee_left_adc.offset;

    configuration.knee_right_adc_min_value = knee_right_adc.min_value;
    configuration.knee_right_adc_max_value = knee_right_adc.max_value;
    configuration.knee_right_adc_offset = knee_right_adc.offset;

    servo_hip_left_controller.saved = true;
    servo_hip_right_controller.saved = true;

    EEPROM_writeAnything(0, configuration);
}

// Whether or not the platform is actively trying to balance.
// rostopic echo /torso_arduino/balancing/get
ros::Publisher balancing_get_publisher = ros::Publisher("balancing/get", &bool_msg);

// Whether or not the platform is considered upright.
// rostopic echo /torso_arduino/upright
ros::Publisher upright_publisher = ros::Publisher("upright/get", &bool_msg);

// rostopic pub --once /torso_arduino/upright/set std_msgs/Empty
void on_upright_set(const std_msgs::Empty& msg) {
    bool_msg.data = !angle_safety_shutoff;
    upright_publisher.publish(&bool_msg);
    nh.spinOnce();
}
ros::Subscriber<std_msgs::Empty> on_upright_set_sub("upright/set", &on_upright_set);

// rostopic echo /torso_arduino/button
ros::Publisher button_publisher = ros::Publisher("button", &bool_msg);

// rostopic echo /torso_arduino/foot/degrees
ros::Publisher foot_degrees_publisher = ros::Publisher("foot/degrees", &int32_msg);

// rostopic echo /torso_arduino/weight/param/get
ros::Publisher params_publisher = ros::Publisher("weight/param/get", &float32ma_msg);

// rostopic echo /torso_arduino/hip/pid/get
ros::Publisher hip_pid_publisher = ros::Publisher("hip/pid/get", &float32ma_msg);

void enable_balancing(){
    if(!balancing_enabled){
        nh.loginfo("Balancing enabled.");
        balancing_started_time = millis();
        balancing_enabled = true;    
        bool_msg.data = balancing_enabled;
        balancing_get_publisher.publish(&bool_msg);
    }
}

void disable_balancing(bool reset=true){
    if(balancing_enabled){
        nh.loginfo("Balancing disabled.");
        if(reset){
            reset_hip_position();
        }
        balancing_stopped_time = millis();
        balancing_enabled = false;    
        bool_msg.data = balancing_enabled;
        balancing_get_publisher.publish(&bool_msg);
    }
}

void set_hip_position(int pos, bool verbose=false){
    // Since the left and right legs are mirror images of each other, the effective position range is a combination of the hard limits of each.
    // The lower bound is the max hard limit of lower bounds.
    // The upper bound is the min hard limit of the upper bounds.

    pos = constrain(pos, SERVO_LOWER_ABS, SERVO_UPPER_ABS); // 1000-2000

    servo_hip_right_pos = pos;
    servo_hip_left_pos = constrain(2 * SERVO_CENTER_ABS - pos + SERVO_HIP_LEFT_OFFSET, SERVO_LOWER_ABS, SERVO_UPPER_ABS);
    
    servo_hip_right_controller.set_position(servo_hip_right_pos);
    servo_hip_left_controller.set_position(servo_hip_left_pos);

    enable_hip_servos();
    if(verbose){
        nh.loginfo("Servo position set.");
    }

    //else{
        //if(verbose){
            //snprintf(buffer, MAX_OUT_CHARS, "Invalid servo position. Must be between %i and %i.", SERVO_LOWER_ABS, SERVO_UPPER_ABS);
            //nh.loginfo(buffer);
        //}
    //}
}

void increment_hip_position(int amount){
    set_hip_position(servo_hip_right_controller.get_target_position() + amount);
}

void reset_hip_position(){
    set_hip_position(SERVO_CENTER_ABS); // reset hip angle
    
}

void log_balance_params(){
    nh.loginfo("NN controller parameters:");
    dtostrf(balance_controller.w_yeta, 5, 3, yaw_str);
    dtostrf(balance_controller.w_yeta_dot, 5, 3, pitch_str);
    dtostrf(balance_controller.w_theta, 5, 3, roll_str);
    dtostrf(balance_controller.w_theta_dot, 5, 3, d_str);
    dtostrf(balance_controller.w_zeta, 5, 3, e_str);
    snprintf(buffer, MAX_OUT_CHARS, "a = %s b = %s c = %s d = %s e = %s", yaw_str, pitch_str, roll_str, d_str, e_str);
    nh.loginfo(buffer);
    
    nh.loginfo("PID controller parameters:");
    dtostrf(hip_pid_controller.Kp, 5, 3, x_str);
    dtostrf(hip_pid_controller.Ki, 5, 3, y_str);
    dtostrf(hip_pid_controller.Kd, 5, 3, z_str);
    snprintf(buffer, MAX_OUT_CHARS, "p = %s i = %s d = %s", x_str, y_str, z_str);
    nh.loginfo(buffer);

    dtostrf(knee_left_adc.get_percent(), 5, 3, x_str);
    dtostrf(knee_left_adc.offset, 5, 3, y_str);
    snprintf(buffer, MAX_OUT_CHARS,
        "KDL: min = %i max = %i offset = %s value = %i (%s)",
        knee_left_adc.min_value, knee_left_adc.max_value, y_str, knee_left_adc.last_value, x_str);
    nh.loginfo(buffer);

    dtostrf(knee_right_adc.get_percent(), 5, 3, x_str);
    dtostrf(knee_right_adc.offset, 5, 3, y_str);
    snprintf(buffer, MAX_OUT_CHARS,
        "KDR: min = %i max = %i offset = %s value = %i (%s)",
        knee_right_adc.min_value, knee_right_adc.max_value, y_str, knee_right_adc.last_value, x_str);
    nh.loginfo(buffer);

}

// max forward
// rostopic pub --once /torso_arduino/servo/hip/set std_msgs/Int16 1275
// max backward
// rostopic pub --once /torso_arduino/servo/hip/set std_msgs/Int16 1500
// extreme left backward, don't use this
// rostopic pub --once /torso_arduino/servo/hip/set std_msgs/Int16 1725
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
void loop() {

    // Toggle status LED to indicate we're doing something.
    if(millis() - last_blink_time >= 500){
        last_blink_time = millis();
        digitalWrite(STATUS_LED_PIN, !digitalRead(STATUS_LED_PIN));
    }
    
    // Update push button state. High=unpressed, Low=pressed.
    if(digitalRead(PUSH_BUTTON_PIN) != last_pushbutton_state){
        last_pushbutton_state = digitalRead(PUSH_BUTTON_PIN);

        bool_msg.data = last_pushbutton_state;
        button_publisher.publish(&bool_msg);
        nh.spinOnce();
        
        if(last_pushbutton_state){
            nh.loginfo("Pushbutton released.");
        }else{
            nh.loginfo("Pushbutton pressed.");
            
            // On depress, toggle balancing flag.
            if(balance_button_enabled){
                if(balancing_enabled){
                    disable_balancing();
                }else{
                    hip_pid_controller.target = foot_tracker.get_position();
                    enable_balancing();
                }
            }
        }
    }
    
    ////////////////////////////////////////////////////////////////////////////
    // Refresh all sensors.

    ag_sensor.update(); // Update MPU6050 data.
    //if(millis() - last_aaread_time >= 100){
        //last_aaread_time = millis();
        //snprintf(buffer, MAX_OUT_CHARS, "acc:%i", ag_sensor.aaReal.z - last_acc_z);
        //nh.loginfo(buffer);
        //nh.spinOnce();
    //}
    diff_acc_z = ag_sensor.aaReal.z - last_acc_z;
    last_acc_z = ag_sensor.aaReal.z;
    servo_hip_left_controller.update();
    servo_hip_right_controller.update();
    servo_knee_left_controller.update();
    servo_knee_right_controller.update();
    knee_left_adc.update();
    knee_right_adc.update();
    pitch_degrees = -ag_sensor.ypr[1] * 180/M_PI;
    foot_tracker.update_position(calculate_foot_degrees(servo_hip_right_controller.get_actual_position_degrees(), pitch_degrees));

    if(knee_right_adc.get_and_clear_changed()){
        int32_msg.data = knee_right_adc.last_value;
        knee_right_adc_get_publisher.publish(&int32_msg);
        nh.spinOnce();
        Serial.flush();
    }
    if(knee_left_adc.get_and_clear_changed()){
        int32_msg.data = knee_left_adc.last_value;
        knee_left_adc_get_publisher.publish(&int32_msg);
        nh.spinOnce();
        Serial.flush();
    }

    ////////////////////////////////////////////////////////////////////////////
    // Reaction to sensors.

    // If our angle is off by more than a set threshold, than it means we've fallen over, so stop updating the servos as a safety mechanism.
    angle_safety_shutoff = abs(foot_tracker.get_position()) > SERVO_SHUTOFF_BACKWARDS_ANGLE;
    if(angle_safety_shutoff_enabled && angle_safety_shutoff && balancing_enabled){
        
        dtostrf(abs(foot_tracker.get_position()), 5, 3, x_str);
        dtostrf(SERVO_SHUTOFF_BACKWARDS_ANGLE, 5, 3, y_str);
        snprintf(buffer, MAX_OUT_CHARS, "Safety shutoff angle exceeded. Foot angle %s has exceeded max angle %s.", x_str, y_str);
        nh.loginfo(buffer);

        disable_balancing();
        nh.spinOnce();
        Serial.flush();
    }
    
    // Publish change in upright.
    if(angle_safety_shutoff != last_angle_safety_shutoff) {
        bool_msg.data = !angle_safety_shutoff;
        upright_publisher.publish(&bool_msg);
        nh.spinOnce();
        Serial.flush();
    }
    
    // Keep our pitch balanced.
    if(balancing_enabled && millis() - servo_last_set_time > 10){ // Update balance 100 times a second. TODO:increase?
        // Get our weight action.
        // Controller returns float in [-1:+1].
        // We scale this to the true maximum control signal, representing a change of position from -1000 to 1000.
        // Note the actual positions are offset between 1000 to 2000.
        //balance_action = balance_controller.step(get_yeta_bounded(), get_yeta_dot_bounded(), get_theta_bounded(), get_theta_dot_bounded());
        //increment_hip_position(int(balance_action * 1000.));
        balance_action = hip_pid_controller.get_value(foot_tracker.get_position());
        if(millis() - foot_log_time >= 1000){
            dtostrf(hip_pid_controller.target, 5, 3, x_str);
            dtostrf(hip_pid_controller.last_actual, 5, 3, y_str);
            dtostrf(balance_action, 5, 3, z_str);
            snprintf(buffer, MAX_OUT_CHARS, "target = %s, actual = %s, balance_action = %s", x_str, y_str, z_str);
            nh.loginfo(buffer);
        }
        set_hip_position(balance_action);
    }

    // Turn off servos if unused for more than a few seconds.
    // This is a safety measure. Even when idling, and not under load, the servos will get quite warm.
    // When under load, the servos can get considerably hot.
    if(servo_hips_active && millis() - servo_last_set_time > 10000){
        disable_hip_servos();
        nh.loginfo("Hip servos disabled due to inactivity.");
    }
    
    // DEBUG output.
    //if(millis() - last_ag_read_time >= 1000){
        //last_ag_read_time = millis();
    
        //dtostrf(ag_sensor.ypr[0] * 180/M_PI, 5, 3, yaw_str);
        //dtostrf(pitch_degrees, 5, 3, pitch_str);//dtostrf(-ag_sensor.ypr[1] * 180/M_PI, 5, 3, pitch_str);
        //dtostrf(ag_sensor.ypr[2] * 180/M_PI, 5, 3, roll_str);
        //dtostrf(ag_sensor.ypr_dot[1] * 180/M_PI*1000, 15, 6, d_str);
        //dtostrf(foot_tracker.get_velocity(), 15, 6, e_str); 

        //snprintf(buffer, MAX_OUT_CHARS,
            //"balancing_enabled=%i, angle_safety_shutoff=%i, hip_angle=%i foot_angle=%i foot_vel=%s yaw=%s pitch=%s roll=%s pitch_dot=%s hl1=%i hl2=%i hr1=%i hr2=%i",
            //balancing_enabled,
            //angle_safety_shutoff,
            //servo_hip_right_controller.get_actual_position_degrees(),
            ////calculate_foot_degrees(servo_hip_right_controller.get_actual_position_degrees(), ag_sensor.ypr[1] * 180/M_PI),
            //foot_tracker.get_position(),
            //e_str,//foot_tracker.get_velocity(),
            //yaw_str, // yaw
            //pitch_str, // pitch
            //roll_str, // roll
            //d_str,
            //servo_hip_left_controller.get_lower_feedback_position(),
            //servo_hip_left_controller.get_upper_feedback_position(),
            //servo_hip_right_controller.get_lower_feedback_position(),
            //servo_hip_right_controller.get_upper_feedback_position()
        //);
        //nh.loginfo(buffer);
        
        ////~ dtostrf(servo_weight_shifter.get_velocity(), 15, 6, yaw_str);
        ////~ snprintf(buffer, MAX_OUT_CHARS,
            ////~ "calibration_state=%i millis()=%lu state_change_time=%lu weight lower=%i weight upper=%i weight pos=%i x_vel=%s",
            ////~ servo_weight_shifter.get_calibrate_state(),
            ////~ millis(),
            ////~ servo_weight_shifter._calibrate_state_change_time,
            ////~ servo_weight_shifter.get_lower_feedback_position(),
            ////~ servo_weight_shifter.get_upper_feedback_position(),
            ////~ servo_weight_shifter.get_actual_position(),
            ////~ yaw_str
        ////~ );
        ////~ nh.loginfo(buffer);
         
    //}
    
    nh.spinOnce();
    Serial.flush();

    // Output a heartbeat count to track how long we've been running.
    if(millis() - last_heartbeat_time >= 10000){
        last_heartbeat_time = millis();
        heartbeat_count += 1;
        snprintf(buffer, MAX_OUT_CHARS, "i=%i", heartbeat_count);
        nh.loginfo(buffer);
        nh.spinOnce();
        Serial.flush();
    }
    
    // Output frequent updates.
    if(millis() - foot_log_time >= 1000){
        // Output foot angle.
        foot_log_time = millis();
        int32_msg.data = foot_tracker.get_position();
        foot_degrees_publisher.publish(&int32_msg);
        nh.spinOnce();
        Serial.flush();
        // Output upright status.
        //bool_msg.data = !angle_safety_shutoff;
        //upright_publisher.publish(&bool_msg);
        //nh.spinOnce();
        //Serial.flush();
        // Output balancing button state.
        //bool_msg.data = balance_button_enabled;
        //balancing_button_publisher.publish(&bool_msg);
        //nh.spinOnce();
        //Serial.flush();
    }

    // If calibration variables have changed, then save them to EEPROM.
    if(!servo_hip_left_controller.saved || !servo_hip_right_controller.saved){
        save_configuration();
    }
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

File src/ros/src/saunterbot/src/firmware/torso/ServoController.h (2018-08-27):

#ifndef ServoController_h
#define ServoController_h

#define SERVO_CALIBRATE_POS_DONE 0
#define SERVO_CALIBRATE_POS_GO_CW 1
#define SERVO_CALIBRATE_POS_GO_CCW 2

#define SERVO_FEEDBACK_ITERS 10

//#include <Servo.h>
#include <VarSpeedServo.h>

class ServoController{

private:

    int _pin;
    int _feedback_pin = -1;
    int _lower_pos;
    int _upper_pos;
    int _lower_degree;
    int _upper_degree;
    int _pos;
    int _default_pos;
    unsigned long _pos_set_time = 0;
    
    // If non-zero, the number of seconds before powering the servo off after position set.
    // This is a useful safety mechanism when the servo is under heavy load and we want to auto-shutoff to prevent overheating.
    unsigned long _power_down_seconds = 0;
    
    int _weight_pos_sensor_low = -1;
    int _weight_pos_sensor_high = -1;
    int _calibrate_state = SERVO_CALIBRATE_POS_DONE;
    
    //unsigned last_feedback_read_time = 0;
    
    int _pos_feedback;
    int _last_pos_feedback;
    unsigned long _last_pos_feedback_time = 0; // ms
    int _lower_pos_feedback;
    int _upper_pos_feedback;
    float _pos_velocity = 0;

    int adc_min_value = 10000;
    int adc_max_value = 0;
    int adc_sum = 0;
    int adc_value;
    
    uint8_t _speed = 0; // 0=full, 1=minium, 255=maximum

public:

    VarSpeedServo _servo;
    bool enabled = false;
    bool feedback_enabled = false;
    unsigned long _calibrate_state_change_time = 0;
    
    bool saved = true;

    ServoController(int pin, int lower_pos, int upper_pos, int default_pos=1500, int feedback_pin=0, int lower_degree=-45, int upper_degree=45){
        _pin = pin;
        _lower_pos = lower_pos;
        _lower_pos_feedback = lower_pos;
        _upper_pos = upper_pos;
        _upper_pos_feedback = upper_pos;
        _pos = default_pos;
        _default_pos = default_pos;
        _feedback_pin = feedback_pin;
        _lower_degree = lower_degree;
        _upper_degree = upper_degree;
        if(_feedback_pin > 0){
            feedback_enabled = true;
        }
    }
    
    void calibrate_position_feedback(){
        if(!feedback_enabled){
            // Do no calibration if there's nothing to calibrate.
            return;
        }
        _calibrate_state = SERVO_CALIBRATE_POS_GO_CW;
        _calibrate_state_change_time = millis();
        power_on();
    }
    
    void power_on(){
        enabled = true;
        _servo.attach(_pin);
        _servo.write(_pos, _speed);
    }

    uint8_t get_speed(){
        return _speed;
    }
    
    void power_off(){
        enabled = false;
        _servo.detach();
    }
    
    void set_position(int pos, uint8_t speed=128){
        _speed = speed;
        _pos = constrain(pos, _lower_pos, _upper_pos);
        _pos_set_time = millis();
    }
    
    void set_power_down_seconds(unsigned long s){
        _power_down_seconds = s;
    }
    
    void set_min_position(){
        _pos = _lower_pos;
    }
    
    void set_max_position(){
        _pos = _upper_pos;
    }

    int get_target_position(){
        return _pos;
    }
    
    int get_actual_position(){
        return _pos_feedback;
    }
    
    int get_actual_position_degrees(){
        return map(_pos_feedback, _lower_pos, _upper_pos, _lower_degree, _upper_degree);
    }
    
    int get_lower_feedback_position(){
        return _lower_pos_feedback;
    }
    
    int get_upper_feedback_position(){
        return _upper_pos_feedback;
    }
    
    void set_feedback_positions(int lower, int upper){
        if(lower){
            _lower_pos_feedback = lower;
        }
        if(upper){
            _upper_pos_feedback = upper;
        }
    }
    
    int read_position_feedback(){
        // We switch to this 2.56V reference (Mega only) because our servo potentiometer outputs, at most, a 1.7V signal
        // which results in a very 200 position range of readings when using the default 5V reference.
        // By lowering the reference, we increase the accuracy of the ADC reading and double the number of positions.
        // https://www.arduino.cc/reference/en/language/functions/analog-io/analogreference/
        analogReference(INTERNAL2V56);
        // Take our reading, performing a simple filter that minimizes noise
        // by taking 5 readings, excluding the lower and upper extremes and then averaging the rest.
        adc_sum = 0;
        adc_min_value = 10000;
        adc_max_value = 0;
        for(int i=0; i<SERVO_FEEDBACK_ITERS; i+=1){
            adc_value = analogRead(_feedback_pin);
            adc_sum += adc_value;
            adc_min_value = min(adc_min_value, adc_value);
            adc_max_value = max(adc_max_value, adc_value);
        }
        adc_sum -= adc_min_value;
        adc_sum -= adc_max_value;
        adc_value = adc_sum/(SERVO_FEEDBACK_ITERS-2);
        // Set it back to default when we're done, so we don't screw up ADC readings for something else that expects 5V.
        analogReference(DEFAULT);
        return adc_value;
    }
    
    float get_velocity(){
        if(isnan(_pos_velocity)){
            return 0;
        }
        return _pos_velocity;
    }
    
    int get_calibrate_state(){
        return _calibrate_state;
    }
    
    void update(){
        if(_calibrate_state != SERVO_CALIBRATE_POS_DONE){
            // Run calibration routine until complete.
            power_on();
            if(_calibrate_state == SERVO_CALIBRATE_POS_GO_CW){
                // Moving clockwise.
                _pos = _lower_pos;
                _servo.write(_pos);
                if(millis() - _calibrate_state_change_time >= 3000){
                    // After 3 seconds, even a slow servo should have received an endstop.
                    // so switch to next state.
                    _calibrate_state = SERVO_CALIBRATE_POS_GO_CCW;
                    _calibrate_state_change_time = millis();
                    _lower_pos_feedback = read_position_feedback();
                    saved = false;
                }
            }else if(_calibrate_state == SERVO_CALIBRATE_POS_GO_CCW){
                // Moving counter clockwise.
                _pos = _upper_pos;
                _servo.write(_pos);
                if(millis() - _calibrate_state_change_time >= 3000){
                    // After 3 seconds, even a slow servo should have received an endstop.
                    // so switch to next state.
                    _calibrate_state = SERVO_CALIBRATE_POS_DONE;
                    _calibrate_state_change_time = millis();
                    _upper_pos_feedback = read_position_feedback();
                    saved = false;
                    _pos = _default_pos;
                    _servo.write(_pos);
                }
            }
        }else if(enabled){
            //_servo.write(_pos, _speed); //TODO:fix? interferes with VarSpeedServo interrupts?
            if(feedback_enabled){
                // Note, due to noise on the line, the measure position can vary by +/- 10 positions.
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

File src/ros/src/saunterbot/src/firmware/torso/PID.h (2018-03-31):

// Variables for Time Keeper function:
#define PID_LOOP_MS 5

#define PID

class PIDController{
    
    private:
    
        float lastpitch;                // Keeps track of error over time
        
        float targetAngle = 0;          // Can be adjusted according to centre of gravity 

        unsigned long thisTime = 0;
        unsigned long lastTime = 0;
        
        int _lower_limit = -255;
        int _upper_limit = +255;
        
        float _scaling_factor = 1.0;
    
    public:
    
        float Kp = 0;//7;                   // (P)roportional Tuning Parameter
        float Ki = 0;//6;                   // (I)ntegral Tuning Parameter        
        float Kd = 0;//3;                  // (D)erivative Tuning Parameter       
        
        float pTerm = 0;
        float iTerm;                    // Used to accumalate error (intergral)
        float dTerm = 0;
        
        PIDController(int lower_limit, int upper_limit, float scaling_factor=1.0){
            _lower_limit = lower_limit;
            _upper_limit = upper_limit;
            _scaling_factor = scaling_factor;
        }
        
        bool is_ready(){
            // We have to limit ourselves from running too fast, otherwise the timeChange rounds out to zero, causing a division error in the dTerm.
            return millis() - lastTime >= PID_LOOP_MS;
        }
        
        void reset(){
            lastTime = 0;
            pTerm = 0;
            iTerm = 0;
            dTerm = 0;
            lastpitch = 0;
        }

        int get_value(float pitch) {            

            // Calculate time since last time PID was called (~10ms)
            //  - - - - - - - - - - - - - - - - - - - - - - - - - - - - - - - - -
            thisTime = millis();
            double timeChange = double(thisTime - lastTime);

            // Calculate Error
            float error = targetAngle - pitch;

            // Calculate our PID terms
            //  - - - - - - - - - - - - - - - - - - - - - - - - - - - - - - - - -
            pTerm = Kp * error;
            iTerm += Ki * error * timeChange;
            dTerm = Kd * (pitch - lastpitch) / timeChange;

            lastpitch = pitch;
            lastTime = thisTime;

            // Combine terms representing the servo position (range 1000-2000).
            //  - - - - - - - - - - - - - - - - - - - - - - - - - - - - - - - - -
            float PIDValue = pTerm + iTerm - dTerm;
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

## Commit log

2018-03-27 Added 3d model frame, initial arduino code.
    [3382g-001-xxx.stp, ArduinoMEGA2560.ipt, ArduinoMEGA2560.stp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]
2018-03-31 Added part docs. Added dynamics docs. Added initial 2d simulator sample code.
    [ArduinoPinout.csv, dc_converter_tray.scad, dc_converter_tray.stl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]
2018-03-31 Updated readme, add illustrations and photos of implemented platform.
    [layout_leg.scad, motors_alturn.scad, motors_alturn_abrs_5314htg_hv.stl]
2018-04-04 Added pymunk and gym simulators for inverted pole models, implemented custom cart table model based on gym example
    [ArduinoANN.ino, matlab_nn_double.ino]
2018-04-12 Updated sims. Added servo and balance controller classes to torso firmware. Added stls for weight shifting mechanism. Added current photos.
    [ArduinoPinout.csv, HS-311 Hitec Standard Servo.SLDPRT, HS-311 Hitec Standard Servo.stl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]
2018-07-31 Added imu reset sub
    [ServoController.h, main.ino]
2018-08-09 Reorganized docs. Added parameter search node for nn and pid controllers.
    [3382g-001-xxx.stp, ArduinoPinout.csv, computers.ods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]
2018-08-15 Added models for knee actuation. Updated firmware for control of knee servos.
    [ArduinoPinout.csv, leg_hip_axle_round.scad, leg_hip_axle_round.stl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]
2018-08-27 Added part docs. Added foot and spring models. Added servo and analog libraries.
    [ArduinoPinout.csv, foot_mock.scad, foot_mock.stl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]
